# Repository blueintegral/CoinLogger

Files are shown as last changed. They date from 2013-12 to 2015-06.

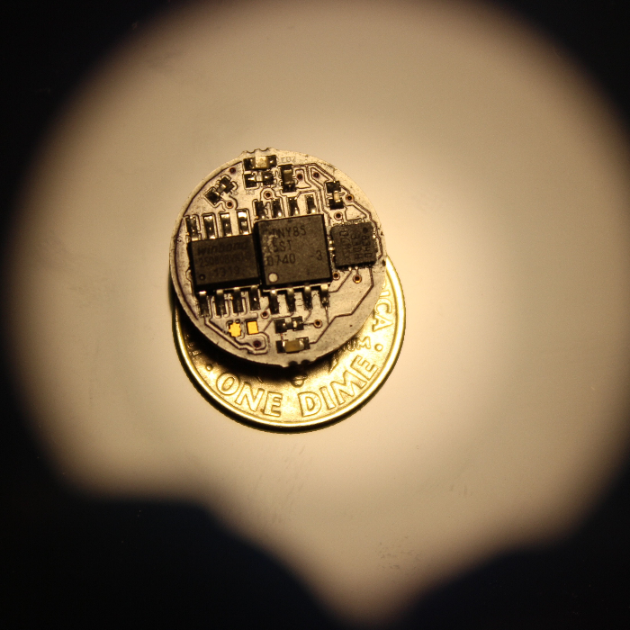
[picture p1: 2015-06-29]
impact.PNG

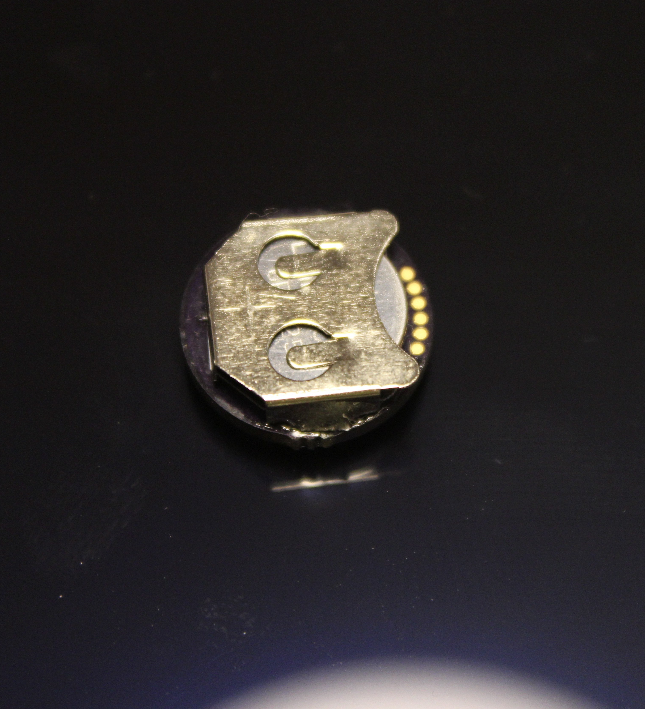
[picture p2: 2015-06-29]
impactback.PNG

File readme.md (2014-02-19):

CoinLogger
==========

CoinLogger is a US Quarter sized data logging platform. The current incantation has an accelerometer on it and 8 MB of Flash storage. It is based on the ATTiny85 microcontroller and also includes a USB port for retrieving the captured data. It was designed with a small size and extremely low power consumption in mind.

NanoLogger is a smaller version of CoinLogger, coming in at about the size of a dime, just over 15mm across. It doesn't have a USB port because there's no room. Instead, you need something like this: https://www.sparkfun.com/products/9235. The battery is smaller, so the battery life is substantially less, and programming and reading data off the device is done via small pads below the battery. This is best done with pogo pins, or you can solder to them. NanoLogger was designed to sacrifice some usability in exchange for an extremely small size.

Uses:
-----
* Amateur rocketry
* Tracking and alerting upon concussions in impact sports
* Characterizing your favorite rollercoaster
* Whatever else you can think of

Future Plans:
-------------
* Add versions with more/different sensors
* Make it even smaller
* Make a version that uses energy harvesting and remove the need for a battery
* Add a low power transciever?
* Move to FRAM instead of Flash, since FRAM can be lower power

Current State:
--------------
Version 1.1 of the boards has been fabbed and is being tested. Firmware is still being written. A program to pull data off the device over USB is also under development. 

Fabbed v1.1 CoinLogger:
Assembled v1.1 front
Assembled v1.1 back

Fabbed v1 NanoLogger:

Assembled NanoLogger front
Assembled NanoLogger back

Old v1:

Fabbed v1

Breadboarded circuit:

Breadboarded circuit

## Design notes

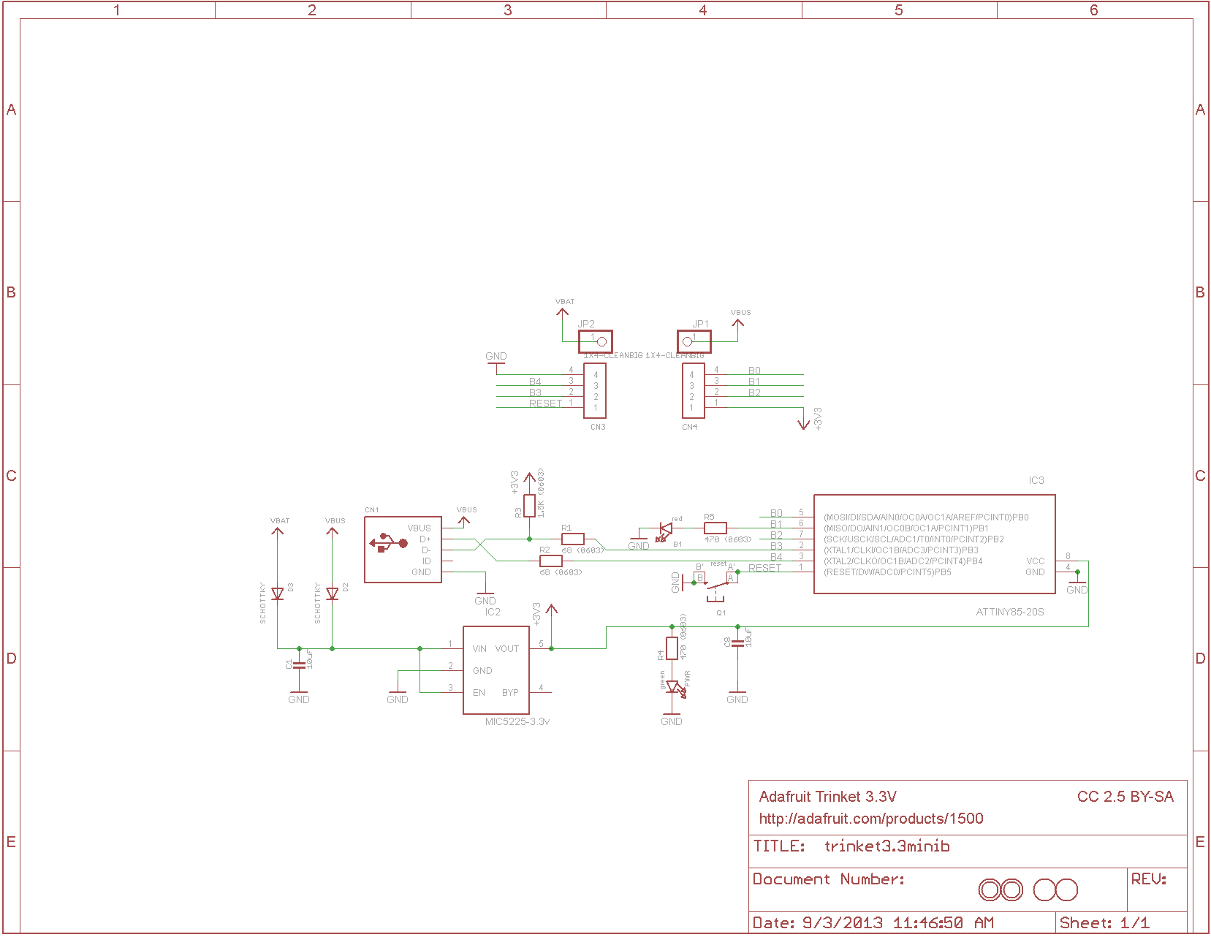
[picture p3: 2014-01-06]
datasheets/adafruit_products_trinket3.png

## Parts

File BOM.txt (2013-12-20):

Partlist

Exported from CoinLogger.sch at 12/19/2013 10:44:44 PM

EAGLE Version 6.2.0 Copyright (c) 1988-2012 CadSoft

Assembly variant: 

Part     Value           Device                  Package        Library  Sheet

BAT2                     BATTERY20SMD            BATTCON_20MM   SparkFun 1
C1       10uF            CAP0402-CAP             0402-CAP       SparkFun 1
C2       0.1uF           CAP0402-CAP             0402-CAP       SparkFun 1
C3       10uF            CAP0402-CAP             0402-CAP       SparkFun 1
IC1      TINY11S         TINY11S                 SOIC8          atmel    1
JP1      USB_MICROB_PLUG USB_MICROB_PLUG         MICRO-B-RA-SMT SparkFun 1
JP2                      M061X06-SMD_EDGE_FEMALE 1X06-SMD_EDGE  SparkFun 1
LED1                     LED0603                 LED-0603       SparkFun 1
LED2                     LED0603                 LED-0603       SparkFun 1
R1       68              RESISTOR0402-RES        0402-RES       SparkFun 1
R2       68              RESISTOR0402-RES        0402-RES       SparkFun 1
R3       470             RESISTOR0402-RES        0402-RES       SparkFun 1
R4       1.5k            RESISTOR0402-RES        0402-RES       SparkFun 1
R5       10k             RESISTOR0402-RES        0402-RES       SparkFun 1
R6       470             RESISTOR0402-RES        0402-RES       SparkFun 1
U$1      W25Q80BV        W25Q80BV                SOIC8          W25Q80BV 1
U4       LIS331          LIS331                  LGA16-3MM      SparkFun 1

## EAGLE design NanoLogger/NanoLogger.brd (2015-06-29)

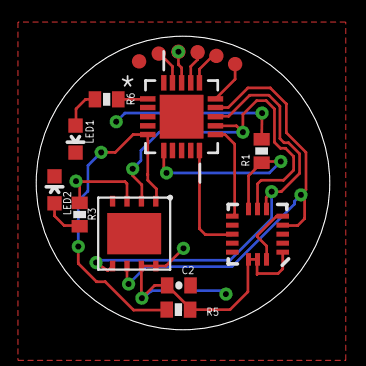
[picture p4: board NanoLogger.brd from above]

Board: 4 copper layers, 16.3 x 16.3 mm, 17 parts (1 on the bottom side), 16 nets.

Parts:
/RESET: TPTP08R; TP08R
C2: 0.1uF; 0402-CAP
GND: TPTP08R; TP08R
LED1, LED2: LED-0603
MISO: TPTP08R; TP08R
MOSI: TPTP08R; TP08R
R1, R5: 10k; 0402-RES
R3, R6: 470; 0402-RES
SCK: TPTP08R; TP08R
U1: ATTINY2313-20MU; QFN50P400X400X80-21N
U4: LIS331; LGA16-3MM
U$1: ML621-TZ1
U$2: MX25U8035EZUI-10G
VCC: TPTP08R; TP08R

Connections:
ADI: U1.13, U4.6, U$2.5
ADO: U1.12, U4.7, U$2.2
ASCK: U1.14, U4.4, U$2.6
GND: C2.2, GND.TP, LED1.C, LED2.C, R1.2, U1.8, U1.21, U4.5, U4.10, U4.12, U4.13, U4.16, U$1.P$2, U$2.4, U$2.9
IMUCS: R1.1, U1.6, U4.8
INT1: U1.10, U4.11
INT2: U1.11, U4.9
MEMCS: R5.1, U1.5, U$2.1
unnamed: R6.2, U1.1
unnamed: /RESET.TP, U1.19
unnamed: LED2.A, R3.1
unnamed: SCK.TP, U1.17
unnamed: LED1.A, R6.1
unnamed: MISO.TP, U1.16
unnamed: MOSI.TP, U1.15
VCC: C2.1, R3.2, R5.2, U1.18, U4.1, U4.14, U4.15, U$1.P$1, U$2.3, U$2.7, U$2.8, VCC.TP

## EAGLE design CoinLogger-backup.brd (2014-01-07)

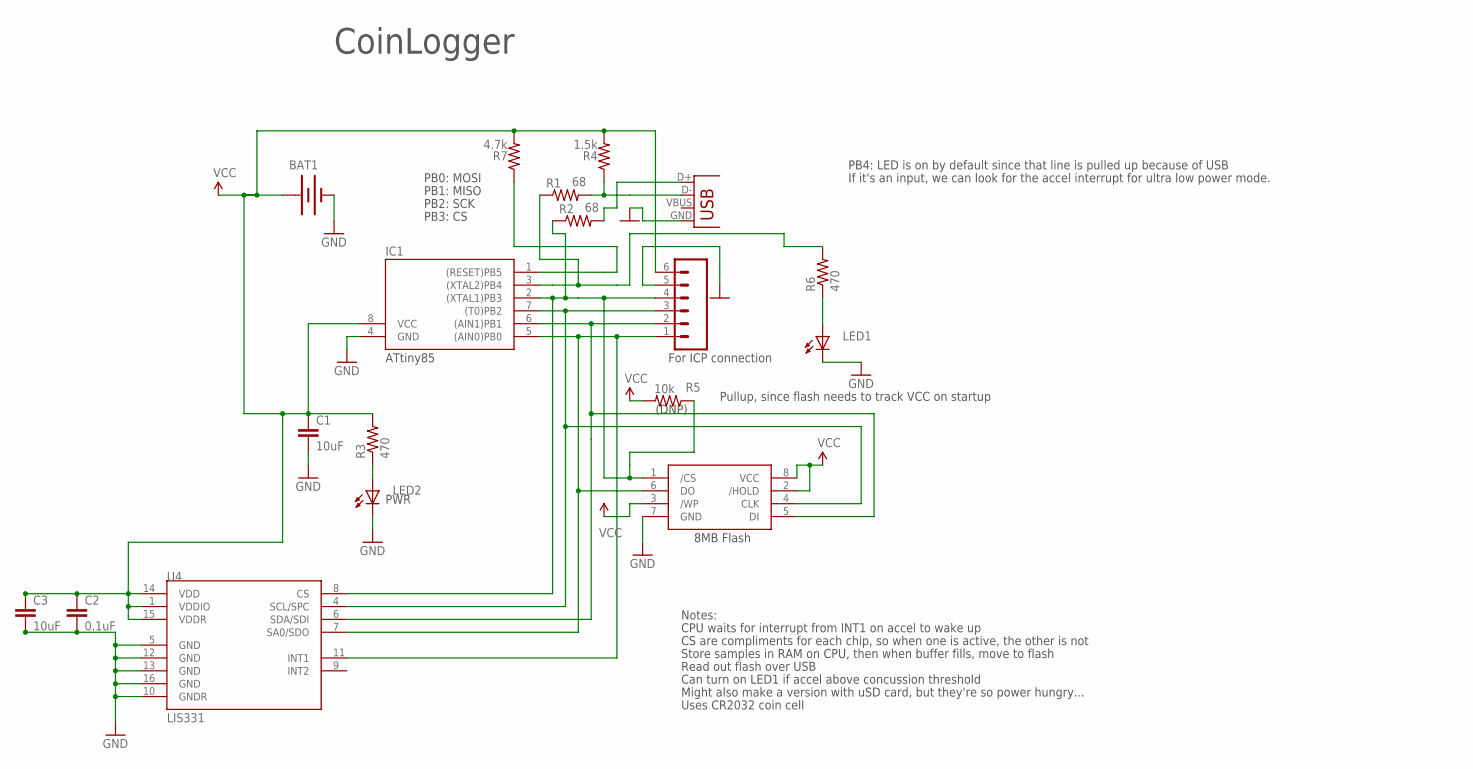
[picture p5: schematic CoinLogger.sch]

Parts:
BAT1: BATTERY20SMD; BATTCON_20MM
C1, C3: 10uF; 0402-CAP
C2: 0.1uF; 0402-CAP
IC1: TINY11S; SOIC8
JP2: M061X06-SMD_EDGE_FEMALE; 1X06-SMD_EDGE
LED1, LED2: LED0603; LED-0603
R1, R2: 68; 0402-RES
R3, R6: 470; 0402-RES
R4: 1.5k; 0402-RES
R5: 10k; 0402-RES
R7: 4.7k; 0402-RES
U4: LIS331; LGA16-3MM
U$1: W25Q80BV; SOIC8
X1: USB-MICROB

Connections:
GND: BAT1.2 (-), C1.2, C2.2, C3.2, IC1.4 (GND), JP2.5, LED1.C, LED2.C, U4.5 (GND), U4.10 (GNDR), U4.12 (GND), U4.13 (GND), U4.16 (GND), U$1.7 (GND), X1.GND
unnamed: R2.2, X1.D+
unnamed: LED2.A, R3.1
unnamed: IC1.2 ((XTAL1)PB3), JP2.4, R2.1, R5.1, U4.8 (CS), U$1.1 (/CS)
unnamed: IC1.7 ((T0)PB2), JP2.3, U4.4 (SCL/SPC), U$1.4 (CLK)
unnamed: IC1.5 ((AIN0)PB0), JP2.1, U4.7 (SA0/SDO), U4.11 (INT1), U$1.6 (DO)
unnamed: IC1.6 ((AIN1)PB1), JP2.2, U4.6 (SDA/SDI), U$1.5 (DI)
unnamed: R1.2, R4.1, X1.D-
unnamed: IC1.1 ((RESET)PB5), R7.1
unnamed: LED1.A, R6.1
unnamed: IC1.3 ((XTAL2)PB4), R1.1, R6.2
VCC: BAT1.1 (+), C1.1, C2.1, C3.1, IC1.8 (VCC), JP2.6, R3.2, R4.2, R5.2, R7.2, U4.1 (VDDIO), U4.14 (VDD), U4.15 (VDDR), U$1.2 (/HOLD), U$1.3 (/WP), U$1.8 (VCC)

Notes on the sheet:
CoinLogger
PWR
ATtiny85
For ICP connection
8MB Flash
Pullup, since flash needs to track VCC on startup
Notes:
CPU waits for interrupt from INT1 on accel to wake up
CS are compliments for each chip, so when one is active, the other is not
Store samples in RAM on CPU, then when buffer fills, move to flash
Read out flash over USB
Can turn on LED1 if accel above concussion threshold
Might also make a version with uSD card, but they're so power hungry...
Uses CR2032 coin cell
PB0: MOSI
PB1: MISO
PB2: SCK
PB3: CS
PB4: LED is on by default since that line is pulled up because of USB
If it's an input, we can look for the accel interrupt for ultra low power mode.
(DNP)

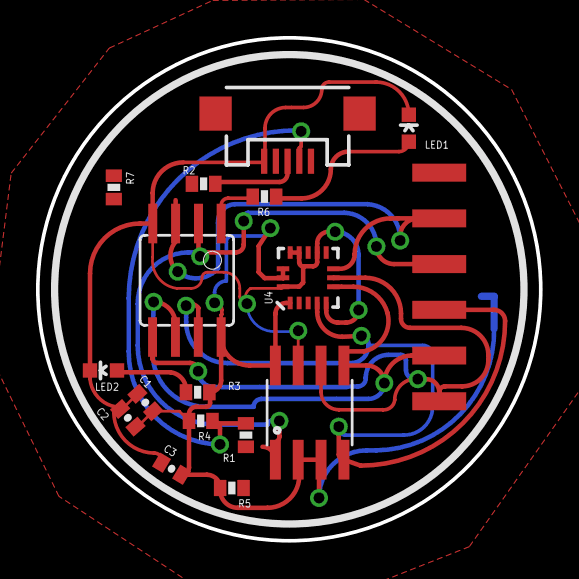
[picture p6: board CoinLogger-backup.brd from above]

Board: 2 copper layers, 27.9 x 27.9 mm, 18 parts (1 on the bottom side), 12 nets.

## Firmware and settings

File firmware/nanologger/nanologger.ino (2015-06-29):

// tinySPI
// Written by Nick Gammon
// March 2013

// ATMEL ATTINY45 / ARDUINO pin mappings
//
//                         +-\/-+
// RESET  Ain0 (D 5) PB5  1|    |8  Vcc
// CLK1   Ain3 (D 3) PB3  2|    |7  PB2 (D 2) Ain1  SCK  / USCK / SCL
// CLK0   Ain2 (D 4) PB4  3|    |6  PB1 (D 1) pwm1  MISO / DO
//                   GND  4|    |5  PB0 (D 0) pwm0  MOSI / DI / SDA
//                         +----+

namespace tinySPI 
  {

  const byte DI   = 0;  // D0, pin 5  Data In
  const byte DO   = 1;  // D1, pin 6  Data Out (this is *not* MOSI)
  const byte USCK = 2;  // D2, pin 7  Universal Serial Interface clock
  const byte SS   = 3;  // D3, pin 2  Slave Select
  
  void begin ()
    {
    digitalWrite (SS, HIGH);  // ensure SS stays high until needed
    pinMode (USCK, OUTPUT);
    pinMode (DO,   OUTPUT);
    pinMode (SS,   OUTPUT);
    USICR = _BV (USIWM0);  // 3-wire mode
    }  // end of tinySPI_begin
    
  // What is happening here is that the loop executes 16 times.
  // This is because the 4-bit counter in USISR is initially zero, and then
  // toggles 16 times until it overflows, thus counting out 8 bits (16 toggles).
  // The data is valid on the clock leading edge (equivalent to CPHA == 0).
  
  byte transfer (const byte b)
    {
    USIDR = b;  // byte to output
    USISR = _BV (USIOIF);  // clear Counter Overflow Interrupt Flag, set count to zero 
    do
      {
      USICR = _BV (USIWM0)   // 3-wire mode
            | _BV (USICS1) | _BV (USICLK)  // Software clock strobe
            | _BV (USITC);   // Toggle Clock Port Pin
      } while ((USISR & _BV (USIOIF)) == 0);  // until Counter Overflow Interrupt Flag set
      
    return USIDR;  // return read data
    }    // end of tinySPI_transfer

  };  // end of namespace tinySPI 
  
  
  
const byte LATCH_PIN = 4;  //D4, pin 3   
const byte ENABLE_PIN = 3; //D3, pin 2 ALSO Slave Select


int current_red = 0;
int current_green = 0;
int current_blue = 0;
int step_time = 20;

int command_mode = 1;

void sendPacket(int, int, int);

void setup() {
    pinMode(LATCH_PIN, OUTPUT);
    
    tinySPI::begin ();
    
    digitalWrite(LATCH_PIN, LOW);
    digitalWrite(ENABLE_PIN, HIGH);  // Turn off shiftbright and clear any garbage in the registers
    delay(1000);
    digitalWrite(ENABLE_PIN, LOW);
    
    sendPacket(120,100,100);
    command_mode = 0;
}

void sendPacket(int red_val, int green_val, int blue_val)
{
      
    tinySPI::transfer(command_mode << 6 | blue_val >> 4);
    tinySPI::transfer(blue_val << 4 | red_val >> 6);
    tinySPI::transfer(red_val << 2 | green_val >> 8);
    tinySPI::transfer(green_val);    
    
    delayMicroseconds(15);
    digitalWrite(LATCH_PIN, HIGH);
    delayMicroseconds(15);
    digitalWrite(LATCH_PIN, LOW);
    
    
}

void loop() {
    
    int red_target = random(0, 1023);
    int green_target = random(0, 1023);
    int blue_target = random(0, 1023);
    
    
    while ((current_red != red_target) || (current_green != green_target) || (current_blue != blue_target))
    {
        if (current_red != red_target)
        {
            current_red = current_red + ((current_red < red_target)? 1 : -1);
        }
        if (current_green != green_target)
        {
            current_green = current_green + ((current_green < green_target)? 1 : -1);
        }
        if (current_blue != blue_target)
        {
            current_blue = current_blue + ((current_blue < blue_target)? 1 : -1);
        }
        
            
        sendPacket(current_red, current_green, current_blue);        
        delay(step_time);
    }
    
    
}

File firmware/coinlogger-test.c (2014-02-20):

/*
 * coinlogger_test.c
 *
 * Created: 1/1/2014 8:51:49 PM
 *  Author: hunter
 * This program tests all the functions of CoinLogger. It turns the LED on for 2 seconds, then reads and write to the accelerometer.
 *  If it works, then the LED is turned on for another 2 seconds. If not, it stays off. It then reads and writes to the EEPROM, and
 *  if that works, it turns the LED on and leaves it on. Otherwise, it stays off.
 */ 


#define F_CPU 9600000UL // Define software reference clock for delay duration
#include <avr/io.h>
#include <stdlib.h>
#include <util/delay.h>
#include <inttypes.h>
#include <avr/interrupt.h>


#define LED PB3
#define MOSI PB0
#define MISO PB1
#define SCLK PB2
#define CS PB3
#define sbi(var, mask)   ((var) |= (uint8_t)(1 << mask))
#define cbi(var, mask)   ((var) &= (uint8_t)~(1 << mask))
#define SCALE 0.0007324  //sets g-level (48 fullscale range)/(2^16bits) = SCALE

#define USIOIF   6
#define USIWM0   4
#define USICS1   3
#define USICLK   1
#define USITC   0
#undef   DDR_WRITE
#define DDR_WRITE   0xE0



//Prototypes
unsigned char spi(unsigned char val);
void accel_read(void);
void accel(void);
void transferLong(unsigned int trans);

//Global Variables
volatile double xaccel = 0;
volatile double yaccel = 0;
volatile double zaccel = 0;


ISR(TIMER1_OVF_vect)
{
	//every ms the acceleration values are printed
	
}

void accel_read(){
	//TCNT1 = 55536;//(8/8MHz)*(65536bits-55536)=0.01s
	accel(); //update LIS registers
	//printf("x=%6.2f,", xaccel);
	//printf("y=%6.2f,", yaccel);
	//printf("z=%6.2f\n\r", zaccel);
}

void accel(void)
{
	uint16_t xl, xh, yl, yh, zl, zh;
	int16_t tempx, tempy, tempz;
	
	//cbi(PORTB, CS);
	PORTB |= 1 << CS;
	spi(0xe8); //read bit | consecutive measure bit | 0x28 = 0xe8
	xl = spi(0x00); //must keep clock moving, so tx another byte
	xh = spi(0x00); //must keep clock moving, so tx another byte
	yl = spi(0x00); //must keep clock moving, so tx another byte
	yh= spi(0x00); //must keep clock moving, so tx another byte
	zl = spi(0x00); //must keep clock moving, so tx another byte
	zh = spi(0x00); //must keep clock moving, so tx another byte
	sbi(PORTB, CS);
	
	tempx = (xl|(xh << 8)); //concatenate low and high bits together, load into signed 16 bit
	xaccel = SCALE*tempx;    //multiply by scale factor for g-level
	tempy = (yl|(yh << 8));
	yaccel = SCALE*tempy;
	tempz = (zl|(zh << 8));
	zaccel = SCALE*tempz;
}


unsigned char spi(unsigned char val)
{
	USIDR = val;
	USISR = (1<<USIOIF);
	do {
		USICR = (1<<USIWM0)|(1<<USICS1)|(1<<USICLK)|(1<<USITC);
	} while ((USISR & (1<<USIOIF)) == 0);
	return USIDR;
}

/*	
static void shft8bit(unsigned char val)
{
	unsigned char cnt;
	sdp8_data &= (~SDP8_CLOCK & ~SDP8_LOAD);   // CLOCK = LOAD = 0 
	for (cnt = 8; cnt; --cnt, val <<= 1) {
		sdp8_data &= ~SDP8_DATA;
		if (val & 0x80) sdp8_data |= SDP8_DATA;
		sdp8_data |= SDP8_CLOCK;
		sdp8_data &= ~SDP8_CLOCK;
	}
}
*/

void transferLong(unsigned int trans){
	/* Transfer the first half */
	spi(trans >> 8);
	/* Transfer the second half */
	spi((uint8_t)trans);
}





int main(void) {

	  //const int msecsDelayPost = 100;

	  // Set up Port B pin 4 mode to output
	  DDRB = 1<<DDB3;
	  DDRB |= _BV(LED);
	  DDRB |= _BV(PB1); /* DO: Data out */
	  DDRB |= _BV(PB2); /* USCK: USI clock */
	  DDRB |= _BV(CS);
	  // Set up Port B data to be all low
	  PORTB = 0;

	  accel_read(); //Get data from accelerometer
	  if (xaccel && yaccel && zaccel) PORTB |= 1 << LED; //Set LED high for 2 seconds if we got nonzero data
	  unsigned char testvar = 0b11111111;
	  while (1) {
		  //Begin test procedure

		  //PORTB ^= 1<<PB3;
		  //_delay_ms (100);
		  spi(testvar--);
		  if(testvar % 10){
			   PORTB |= 1 << LED;
			   _delay_ms(10);
		  } else {
			  PORTB &= ~(1<<LED);
			  _delay_ms(100);
		  }
		   
		  
	  }

	return 0;
}

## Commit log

2014-01-05 Added some test code, started v1.1 of board
2014-01-05 Cleaned up repo organization
    [CoinLogger.GBL, CoinLogger.GBO, CoinLogger.GBS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]
2014-01-06 Board is now v1.1
    [CoinLogger.brd, CoinLogger.sch]
2014-01-07 Lots of fixes, added NanoLogger
    [CoinLogger.brd, NanoLogger.brd, NanoLogger.sch]
2014-01-07 Updated and rerouted V1.1, early nanologger layout
    [CoinLogger-backup.brd, CoinLogger.sch, NanoLogger.brd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]
2014-01-08 NanoLogger is routed and ready for order. 16mm!
    [NanoLogger.brd, NanoLogger.sch]
2014-02-19 Updated readme, test code kinda works now
    [NanoLogger.brd]
2014-05-07 spliced some stuff for an arduino verison
2015-06-29 Route looks better now
    [NanoLogger.brd]
2015-06-29 Quick ERC fix, removed temp files
    [NanoLogger.sch]

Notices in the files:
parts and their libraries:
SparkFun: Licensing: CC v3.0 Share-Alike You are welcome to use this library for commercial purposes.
